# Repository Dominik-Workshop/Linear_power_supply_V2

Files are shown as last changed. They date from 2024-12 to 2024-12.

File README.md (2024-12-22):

# DW3005T - Linear power supply 2

This is the second iteration of my linear power supply project [available on GitHub](https://github.com/Dominik-Workshop/Linear_power_supply), building upon the foundation of my original design. While the first version served as an excellent learning experience, the DW3005T aims to improve upon its predecessor with enhanced performance, better stability, and a more professional design.

## Used tools:
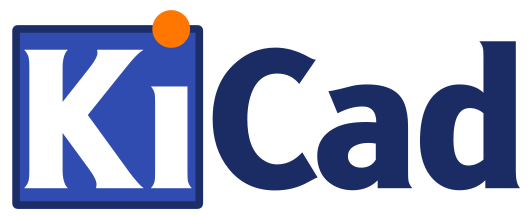
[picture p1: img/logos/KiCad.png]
 &nbsp;&nbsp;&nbsp;&nbsp; &nbsp;&nbsp;&nbsp;&nbsp; 
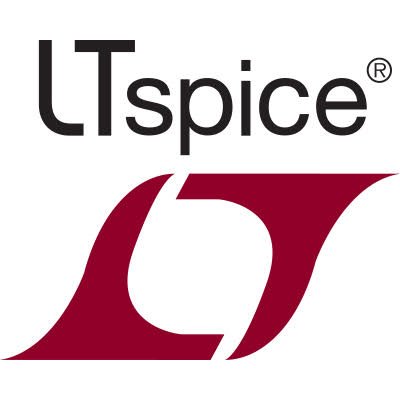
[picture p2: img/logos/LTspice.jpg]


### Project Goals:
- **30V 5A output**
- **Very small output resistance**
- **Precise voltage, current and power measurements**
- **Small output noise**
- **Digital controll** - rotary encoder

## Electronics
### PCBs:
- Power board

<div align="center">
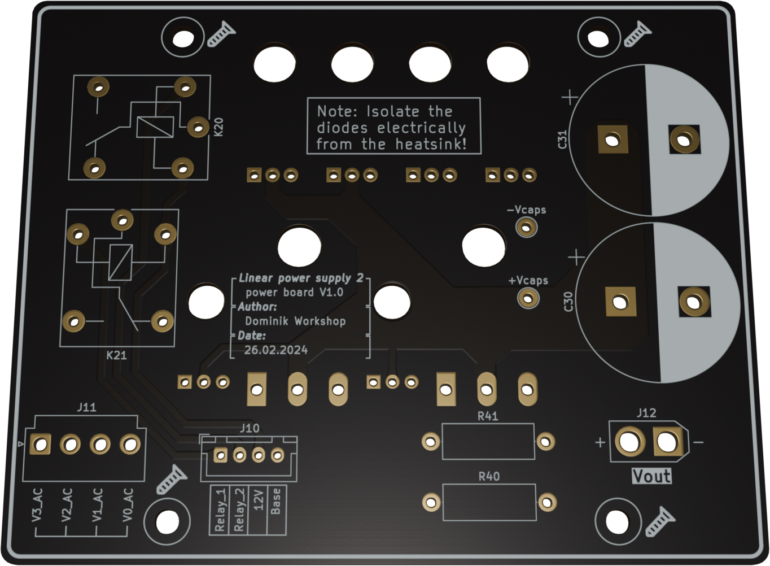
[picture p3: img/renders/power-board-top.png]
  
</div>

&nbsp;

- Control board
> [!WARNING]  
> WORK IN PROGRESS

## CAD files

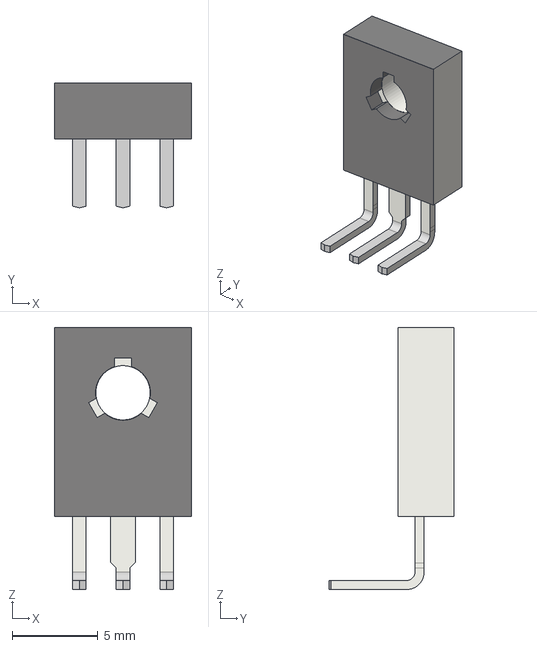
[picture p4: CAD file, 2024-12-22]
pcb/pcb_lib/3d_models/TO-126-3_horizontal_tab_up.step
8.00 x 7.26 x 15.2 mm

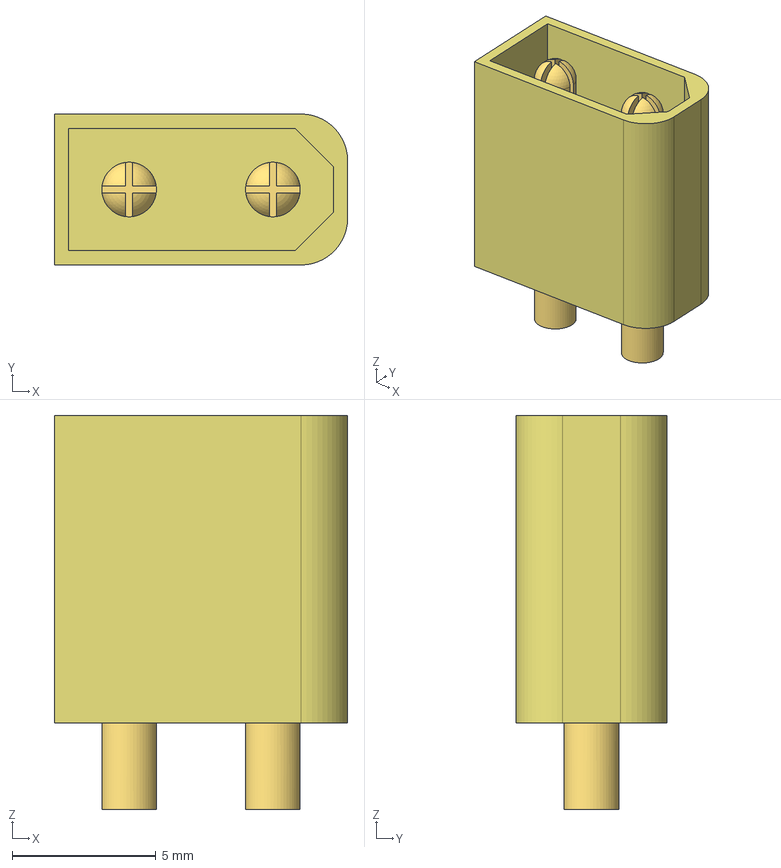
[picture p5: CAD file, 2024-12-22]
pcb/pcb_lib/3d_models/XT30U-M.step
10.2 x 5.25 x 13.7 mm

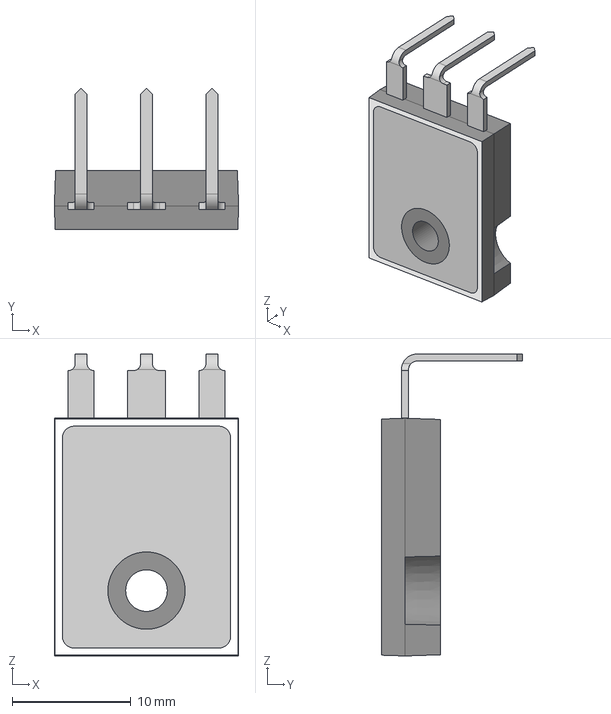
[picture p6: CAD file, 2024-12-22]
pcb/pcb_lib/3d_models/TO-247H.step
15.5 x 11.9 x 25.4 mm

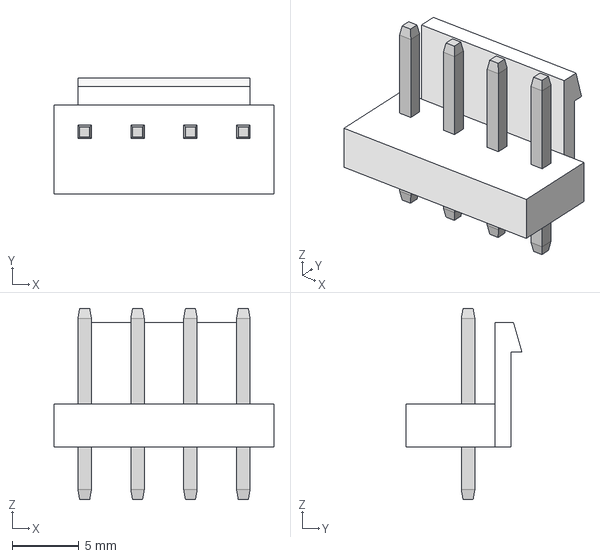
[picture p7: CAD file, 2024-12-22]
pcb/pcb_lib/3d_models/JST B4P_VH.stp
16.5 x 8.69 x 14.3 mm

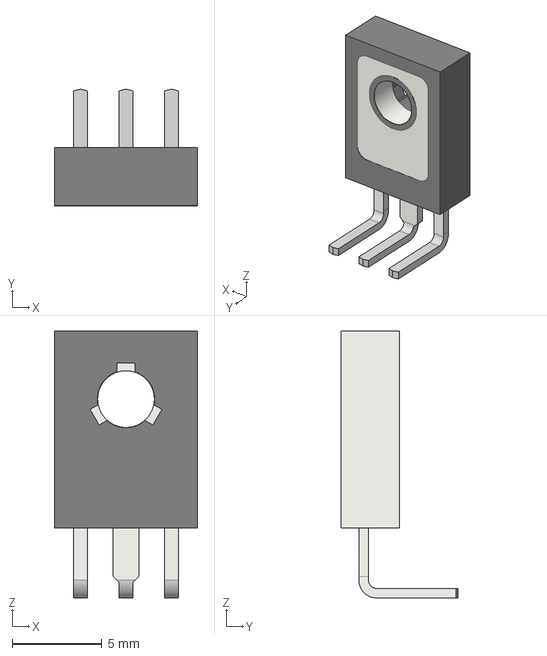
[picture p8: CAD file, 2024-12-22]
pcb/pcb_lib/3d_models/TO-126-3_horizontal_tab_down.step
8.00 x 6.51 x 14.9 mm

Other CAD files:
3d-models/power-board.blend

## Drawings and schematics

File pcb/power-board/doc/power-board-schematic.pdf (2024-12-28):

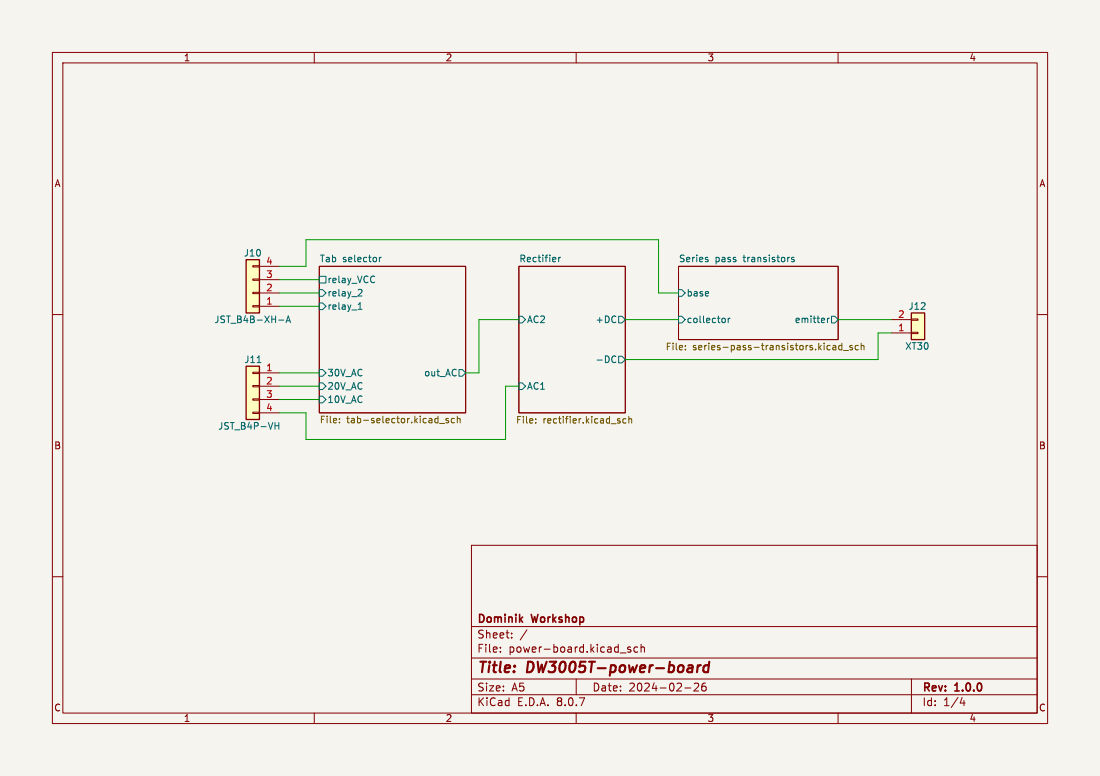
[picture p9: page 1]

emitter Series pass transistors File: series-pass-transistors.kicad_sch

Id: 1/4 Title: DW3005T-power-board

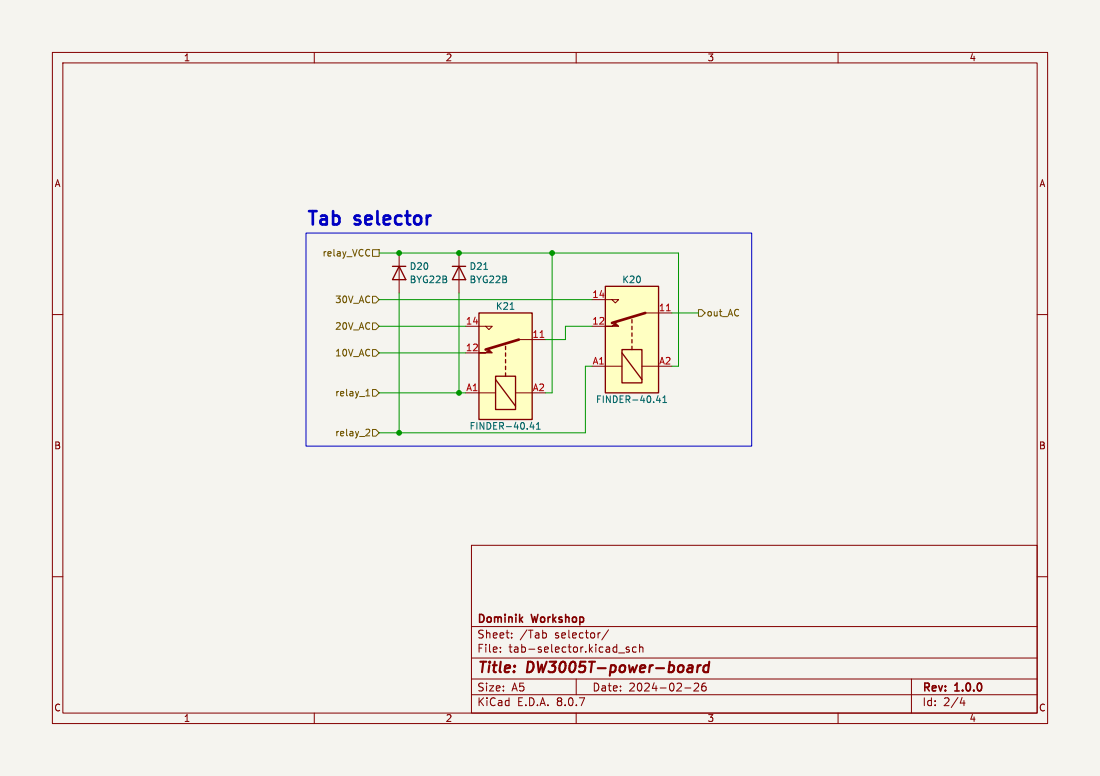
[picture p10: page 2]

Id: 2/4 Title: DW3005T-power-board

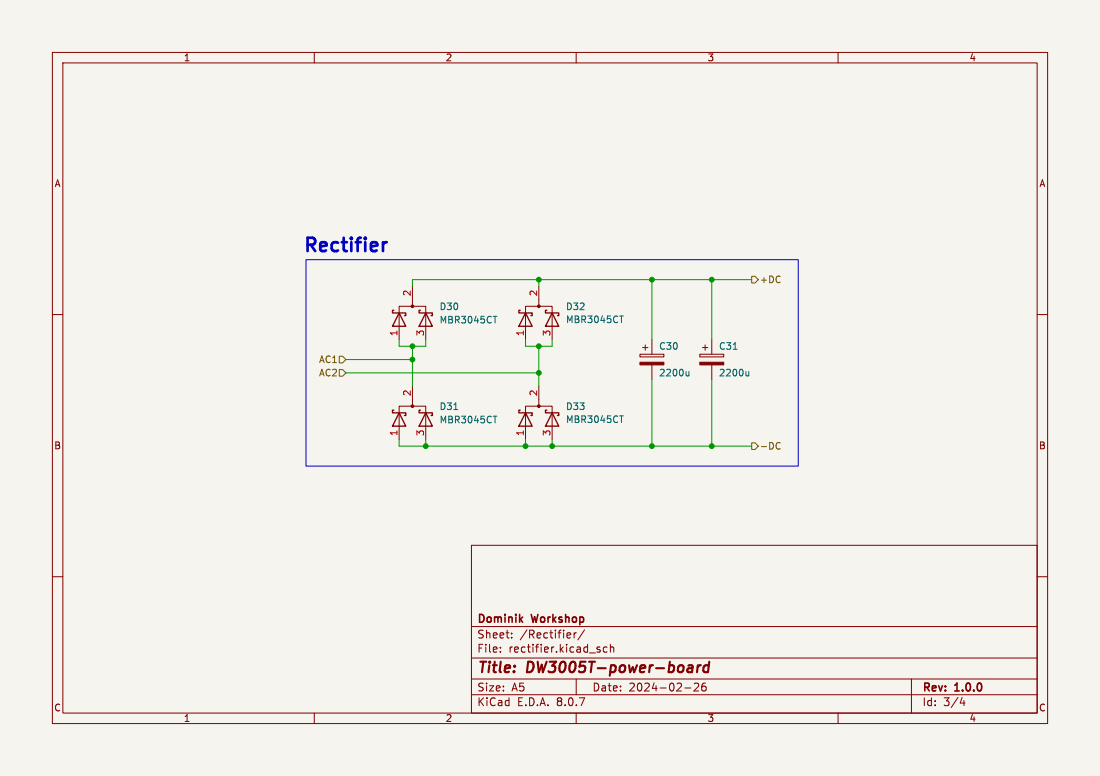
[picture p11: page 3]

Id: 3/4 Title: DW3005T-power-board

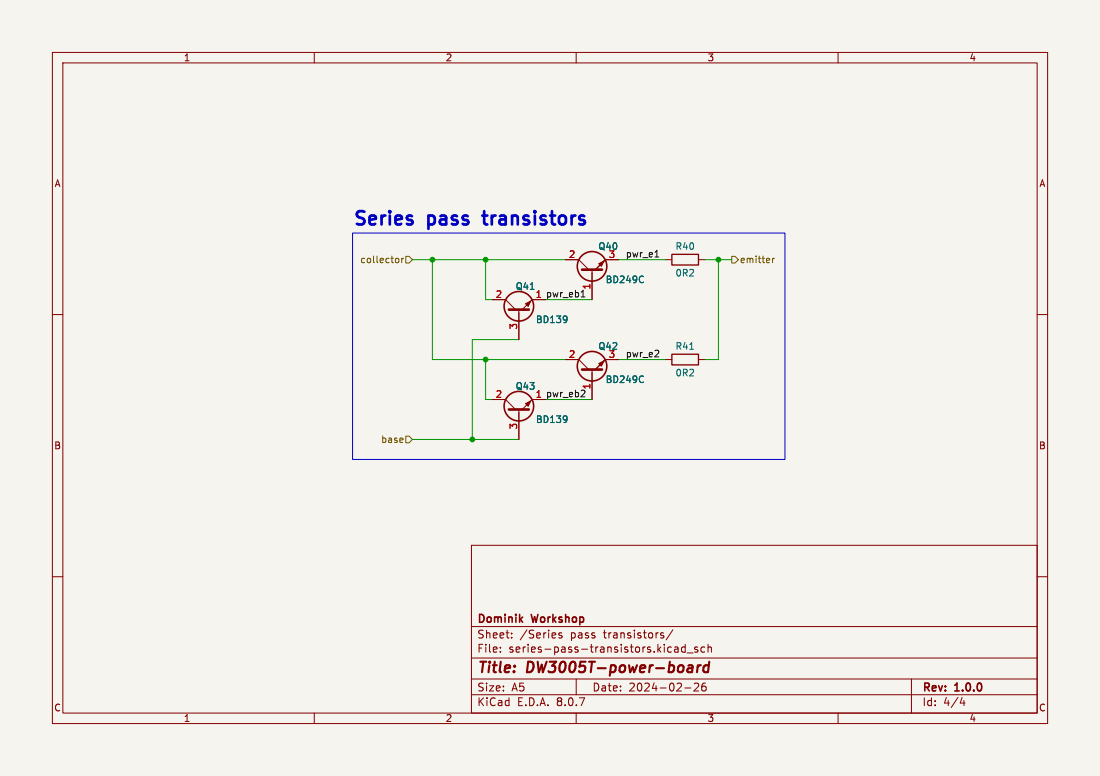
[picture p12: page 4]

Id: 4/4 Title: DW3005T-power-board

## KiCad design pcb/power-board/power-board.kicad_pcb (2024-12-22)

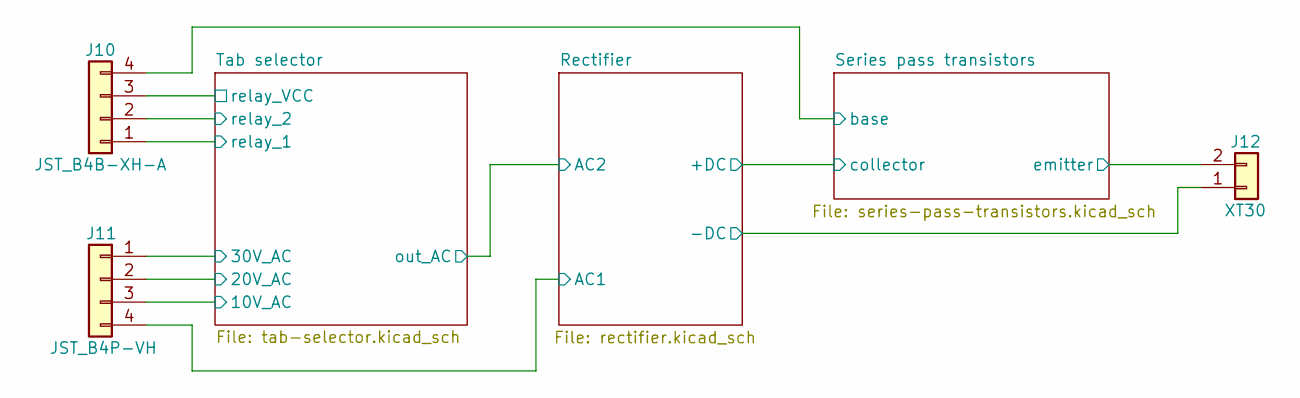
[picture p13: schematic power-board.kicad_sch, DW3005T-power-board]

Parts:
J10: JST_B4B-XH-A; JST_XH_B4B-XH-A_1x04_P2.50mm_Vertical
J11: JST_B4P-VH; JST_VH_B4P-VH_1x04_P3.96mm_Vertical
J12: XT30; AMASS_XT30U-F_1x02_P5.0mm_Vertical

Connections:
/Rectifier/-DC: J12.1; also elsewhere on the board
/Rectifier/AC1: J11.4; also elsewhere on the board
/Series pass transistors/base: J10.4; also elsewhere on the board
/Series pass transistors/emitter: J12.2; also elsewhere on the board
/Tab selector/10V_AC: J11.3; also elsewhere on the board
/Tab selector/20V_AC: J11.2; also elsewhere on the board
/Tab selector/30V_AC: J11.1; also elsewhere on the board
/Tab selector/relay_1: J10.1; also elsewhere on the board
/Tab selector/relay_2: J10.2; also elsewhere on the board
/Tab selector/relay_VCC: J10.3; also elsewhere on the board

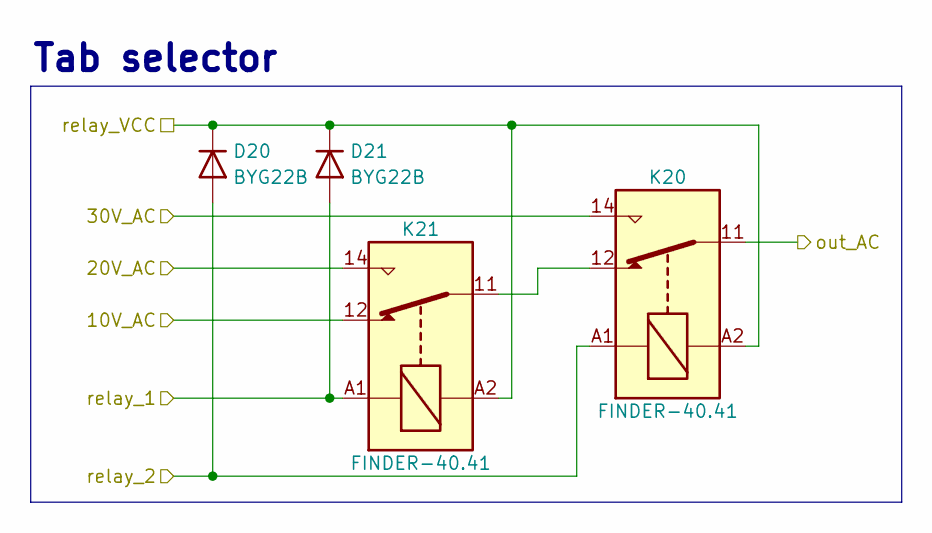
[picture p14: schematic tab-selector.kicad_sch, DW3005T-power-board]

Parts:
D20, D21: BYG22B; D_SMA; MPN BYG22B-E3/TR
K20, K21: FINDER-40.41; Relay_SPDT_Finder_36.11

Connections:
/Rectifier/AC2: K20.11; also elsewhere on the board
/Tab selector/10V_AC: K21.12; also elsewhere on the board
/Tab selector/20V_AC: K21.14; also elsewhere on the board
/Tab selector/30V_AC: K20.14; also elsewhere on the board
/Tab selector/relay_1: D21.2 (A), K21.A1; also elsewhere on the board
/Tab selector/relay_2: D20.2 (A), K20.A1; also elsewhere on the board
/Tab selector/relay_VCC: D20.1 (K), D21.1 (K), K20.A2, K21.A2; also elsewhere on the board
unnamed: K20.12, K21.11

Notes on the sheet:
Tab selector

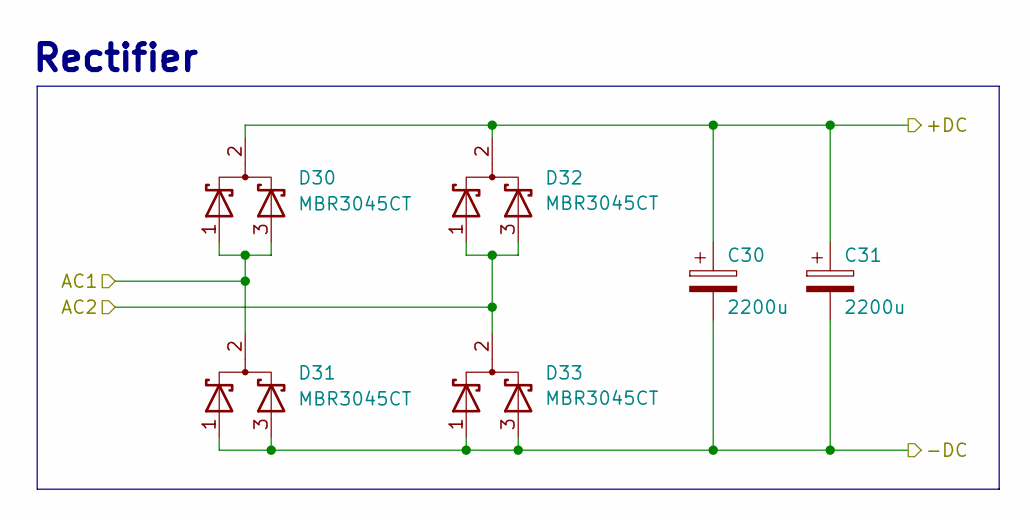
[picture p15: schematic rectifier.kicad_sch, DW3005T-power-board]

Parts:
C30, C31: 2200u; CP_Radial_D22.0mm_P10.00mm_SnapIn
D30, D31, D32, D33: MBR3045CT; TO-220-3_Horizontal_TabUp

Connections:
/Rectifier/+DC: C30.1, C31.1, D30.2 (A), D32.2 (A); also elsewhere on the board
/Rectifier/-DC: C30.2, C31.2, D31.1 (K), D31.3 (K), D33.1 (K), D33.3 (K); also elsewhere on the board
/Rectifier/AC1: D30.1 (K), D30.3 (K), D31.2 (A); also elsewhere on the board
/Rectifier/AC2: D32.1 (K), D32.3 (K), D33.2 (A); also elsewhere on the board

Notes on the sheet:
Rectifier

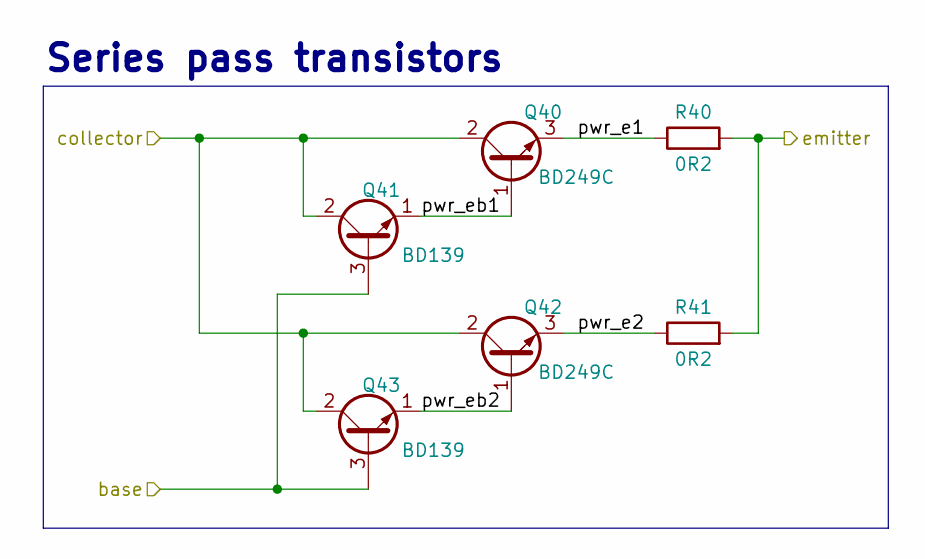
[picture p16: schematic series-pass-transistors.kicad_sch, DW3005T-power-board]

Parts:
Q40, Q42: BD249C; TO-247-3_Horizontal_TabUp
Q41, Q43: BD139; TO-126-3_Horizontal_TabUp
R40, R41: 0R2; R_Axial_DIN0414_L11.9mm_D4.5mm_P15.24mm_Horizontal

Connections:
/Rectifier/+DC: Q40.2 (C), Q41.2 (C), Q42.2 (C), Q43.2 (C); also elsewhere on the board
/Series pass transistors/base: Q41.3 (B), Q43.3 (B); also elsewhere on the board
/Series pass transistors/emitter: R40.2, R41.2; also elsewhere on the board
/Series pass transistors/pwr_e1: Q40.3 (E), R40.1
/Series pass transistors/pwr_e2: Q42.3 (E), R41.1
/Series pass transistors/pwr_eb1: Q40.1 (B), Q41.1 (E)
/Series pass transistors/pwr_eb2: Q42.1 (B), Q43.1 (E)

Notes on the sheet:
Series pass transistors

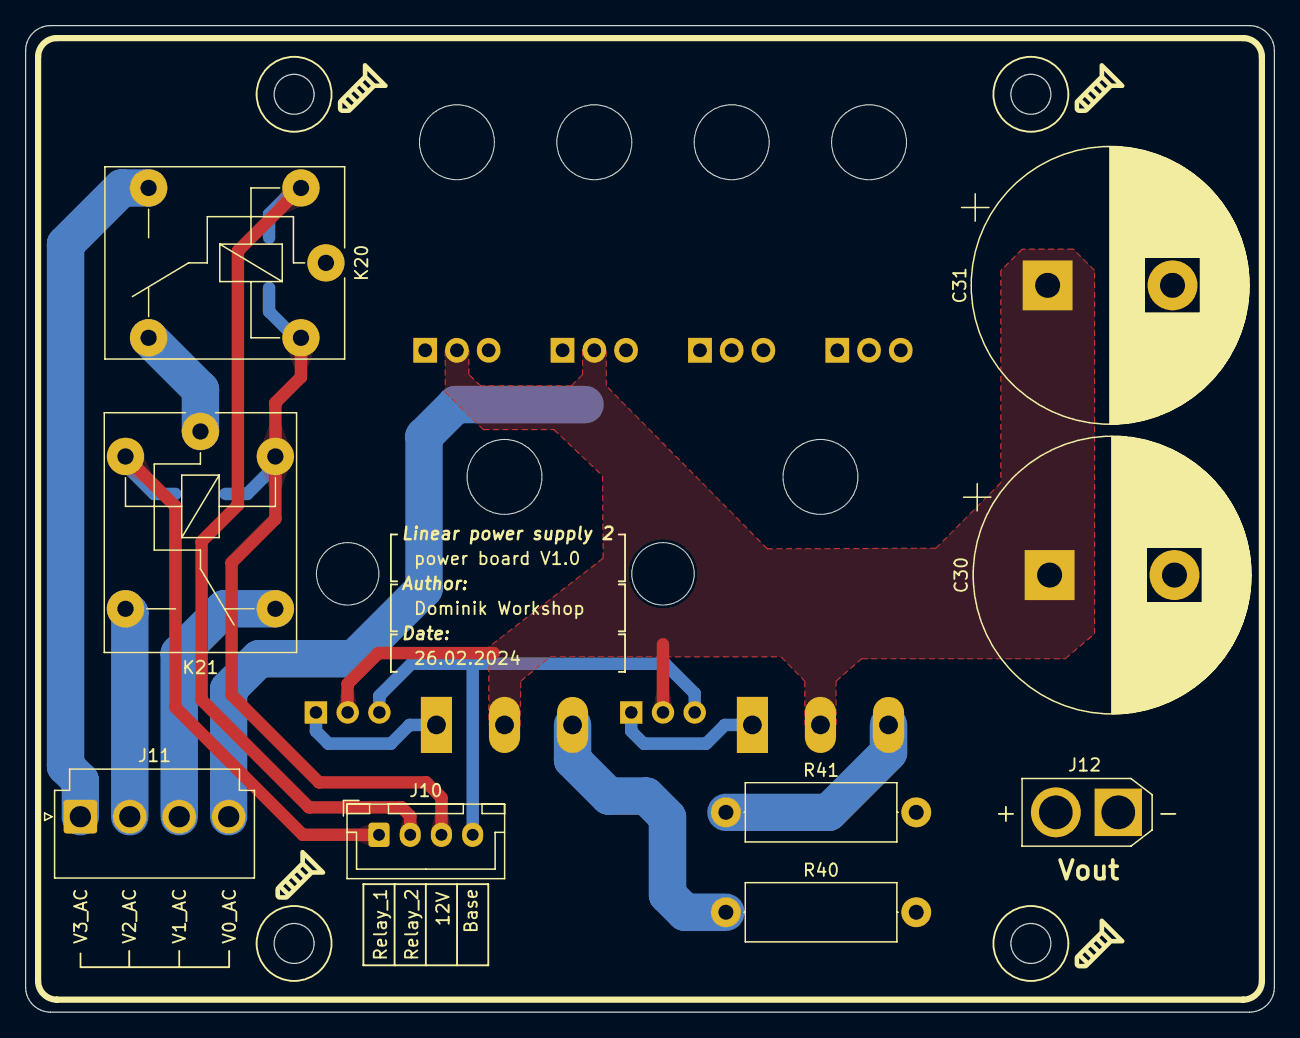
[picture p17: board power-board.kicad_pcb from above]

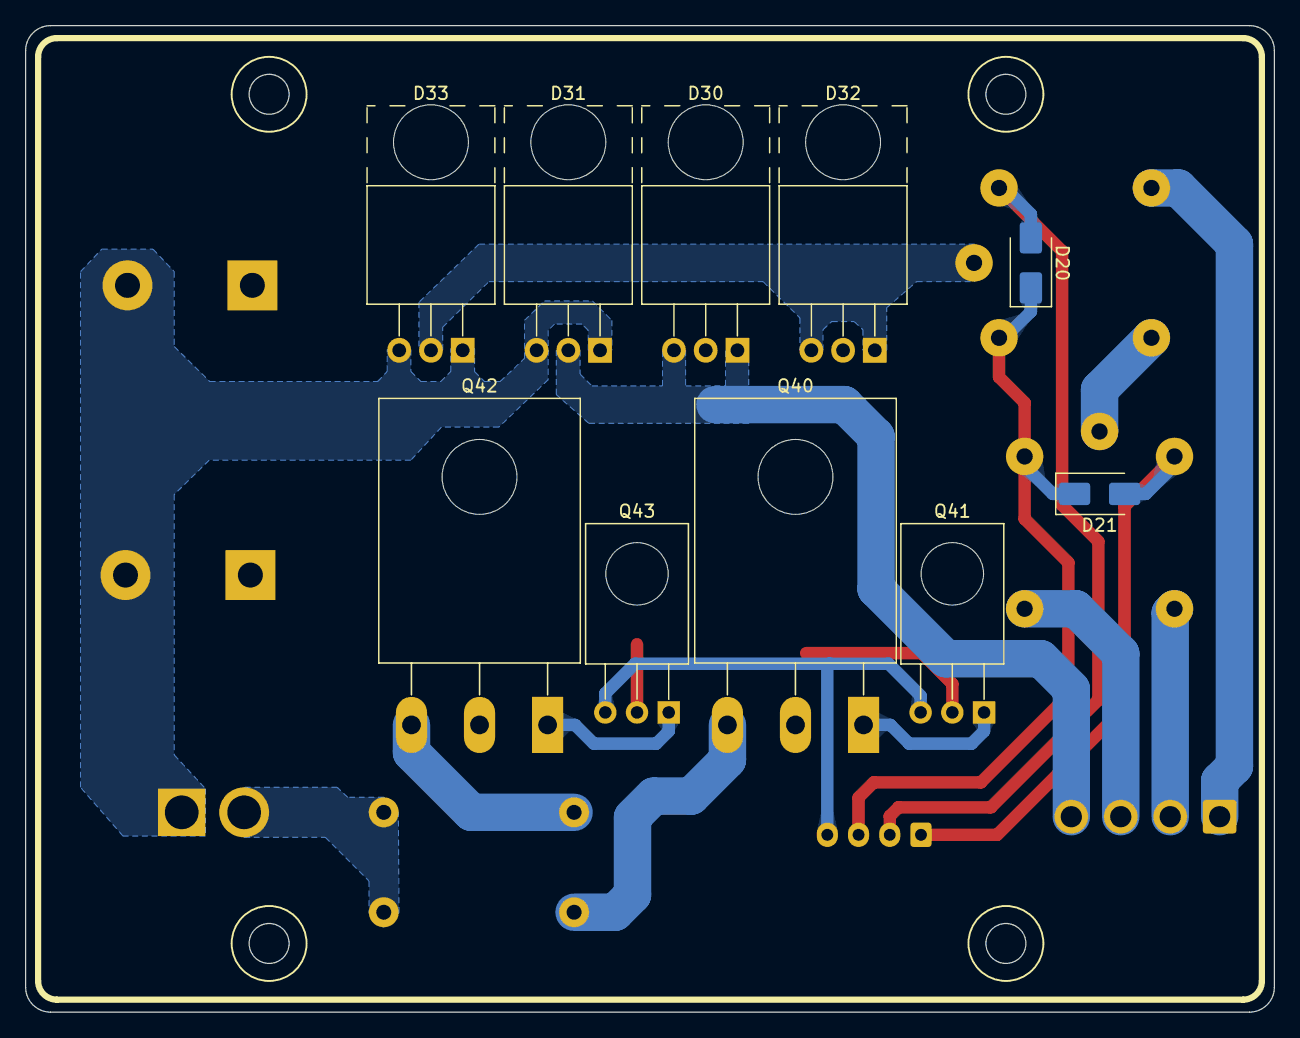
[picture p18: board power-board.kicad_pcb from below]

Board: 2 copper layers, 100.0 x 79.0 mm, 19 parts (10 on the bottom side), 17 nets.

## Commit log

2024-12-21 Add KiCad and LTspice unnecessary files to gitignore
2024-12-22 Add KiCad and LTspice logo in README, update project description
2024-12-22 Add TO126, TO247, JST B4P and XT30 connector 3d models
    [JST B4P_VH.stp, TO-126-3_horizontal_tab_down.step, TO-126-3_horizontal_tab_up.step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]
2024-12-22 Add screw symbol
2024-12-22 Add power-board KiCad design
    [pcb_power.kicad_pcb, pcb_power.kicad_sch, power_transistors.kicad_sch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]
2024-12-22 Add power-board gerber files zip
2024-12-22 Add guide for heatsink drill holes
2024-12-22 Perform minor stylistic changes on power-board schematic, clear DRC
    [pcb_power.kicad_pcb, pcb_power.kicad_sch, rectifier.kicad_sch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]
2024-12-22 Add power-board top view render in README
2024-12-28 Rename power-board KiCad files
    [power-board.kicad_pcb, power-board.kicad_sch, rectifier.kicad_sch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]
2024-12-28 Add CI for power-board PCB
2024-12-28 Add generated schematic PDF, necessary Gerber layers, and 3D model
    [power-board-B_Cu.gbr, power-board-B_Mask.gbr, power-board-B_Paste.gbr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]
